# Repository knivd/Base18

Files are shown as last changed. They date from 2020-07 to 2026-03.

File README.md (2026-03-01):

# Base18
Files for my Base-18 project. <br>
https://www.youtube.com/watch?v=KffhLjCJ9JE <br>
Hackaday page: https://hackaday.io/project/166599-going-8-bit-in-style-the-pic18-computer <br>
It includes a version of the RIDE line editor, a PIC18 monitor (with disassembler!) and file system based on FatFs

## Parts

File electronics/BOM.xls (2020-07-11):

Designator | MPN/SKU | Qty | Link
C1, C2, C5, C7, C8, C10 | CL31B104KBCNNNC | 6 | https://www.digikey.co.uk/products/en?keywords=1276-1017-1-ND
C3, C4 | CC1206JRNPO9BN180 | 2 | https://www.digikey.co.uk/products/en?keywords=311-1152-1-ND
C6, C9, C11 | CL31A106KAHNNNE | 3 | https://www.digikey.co.uk/products/en?keywords=1276-1075-1-ND
D1 | 1N4148W-TP | 1 | https://www.digikey.co.uk/products/en?keywords=1N4148WTPMSCT-ND
J1, J2 | TSM-105-01-F-DV | 2 | https://www.digikey.co.uk/products/en?keywords=SAM12227-ND
J3 | PJ-036AH-SMT-TR | 1 | https://www.digikey.co.uk/products/en?keywords=CP-036AHPJCT-ND
LED1 | CMD15-21VYC/TR8 | 1 | https://www.digikey.co.uk/products/en?keywords=L62207CT-ND
LED2 | CMD15-21VRD/TR8 | 1 | https://www.digikey.co.uk/products/en?keywords=L62301CT-ND
LED3 | CMD15-21VGD/TR8 | 1 | https://www.digikey.co.uk/products/en?keywords=L62305CT-ND
MOD1 | OKL-T/3-W12P-C | 1 | https://www.digikey.co.uk/products/en?keywords=811-2709-1-ND
Q1 | DMP4051LK3 | 1 | https://www.digikey.co.uk/products/en?keywords=DMP4051LK3-13DICT-ND
Q2 | MMUN2233LT1G | 1 | https://www.digikey.co.uk/product-detail/en/on-semiconductor/MMUN2233LT1G/MMUN2233LT1GOSCT-ND/919797
R1, R2, R3, R4, R5, R7, R8, R9, R10, R12, R13, R14, R15, R16, R22, R23, R24 | RC1206JR-0710KL | 17 | https://www.digikey.co.uk/products/en?keywords=311-10KERCT-ND
R18 | RC1206FR-071KL | 1 | https://www.digikey.co.uk/products/en?keywords=311-1.00KFRCT-ND
R19 | RC1206FR-072K15L | 1 | https://www.digikey.co.uk/products/en?keywords=311-2.15KFRCT-ND
R6, R11, R17, R20 | RC1206FR-07300RL | 4 | https://www.digikey.co.uk/products/en?keywords=311-300FRCT-ND
SW1, SW2 | FSMSM | 2 | https://www.digikey.co.uk/product-detail/en/te-connectivity-alcoswitch-switches/FSMSM/450-1140-ND/525812
U1 | PIC18F87K22-I/PT | 1 | https://www.digikey.co.uk/products/en?keywords=PIC18F87K22-I%2FPT-ND
U2 | SN74LVTH573NSR | 1 | https://www.digikey.co.uk/products/en?keywords=296-13300-1-ND
Y1 | ABLS-16.000MHZ-B4-T | 1 | https://www.digikey.co.uk/products/en?keywords=535-10226-1-ND
Z1 | NFE31PT222Z1E9L | 1 | https://www.digikey.co.uk/products/en?keywords=490-2547-1-ND
X1, X2, X3, X4, X5, X6, X7, X8 | Female 2x30 SMT 2.54mm | 8 | https://www.aliexpress.com/item/32798959899.html

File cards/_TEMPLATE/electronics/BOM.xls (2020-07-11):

Designator | MPN/SKU | Qty | Link
X1 | TSW-130-07-G-D | 1 | https://www.digikey.co.uk/products/en?keywords=SAM1028-30-ND

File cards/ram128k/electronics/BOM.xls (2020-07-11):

Designator | MPN/SKU | Qty | Link
X1 | TSW-130-07-G-D | 1 | https://www.digikey.co.uk/products/en?keywords=SAM1028-30-ND
C1, C2, C3 | CL31B104KBCNNNC | 3 | https://www.digikey.co.uk/products/en?keywords=1276-1017-1-ND
U1 | IS61WV1288EEBLL-10TLI | 1 | https://www.digikey.co.uk/products/en?keywords=706-1500-ND
U2 | CD4078BM | 1 | https://www.digikey.co.uk/products/en?keywords=296-41220-1-ND

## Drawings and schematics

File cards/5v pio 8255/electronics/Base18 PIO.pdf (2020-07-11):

# A20 INT0#

# INT2# RESET#

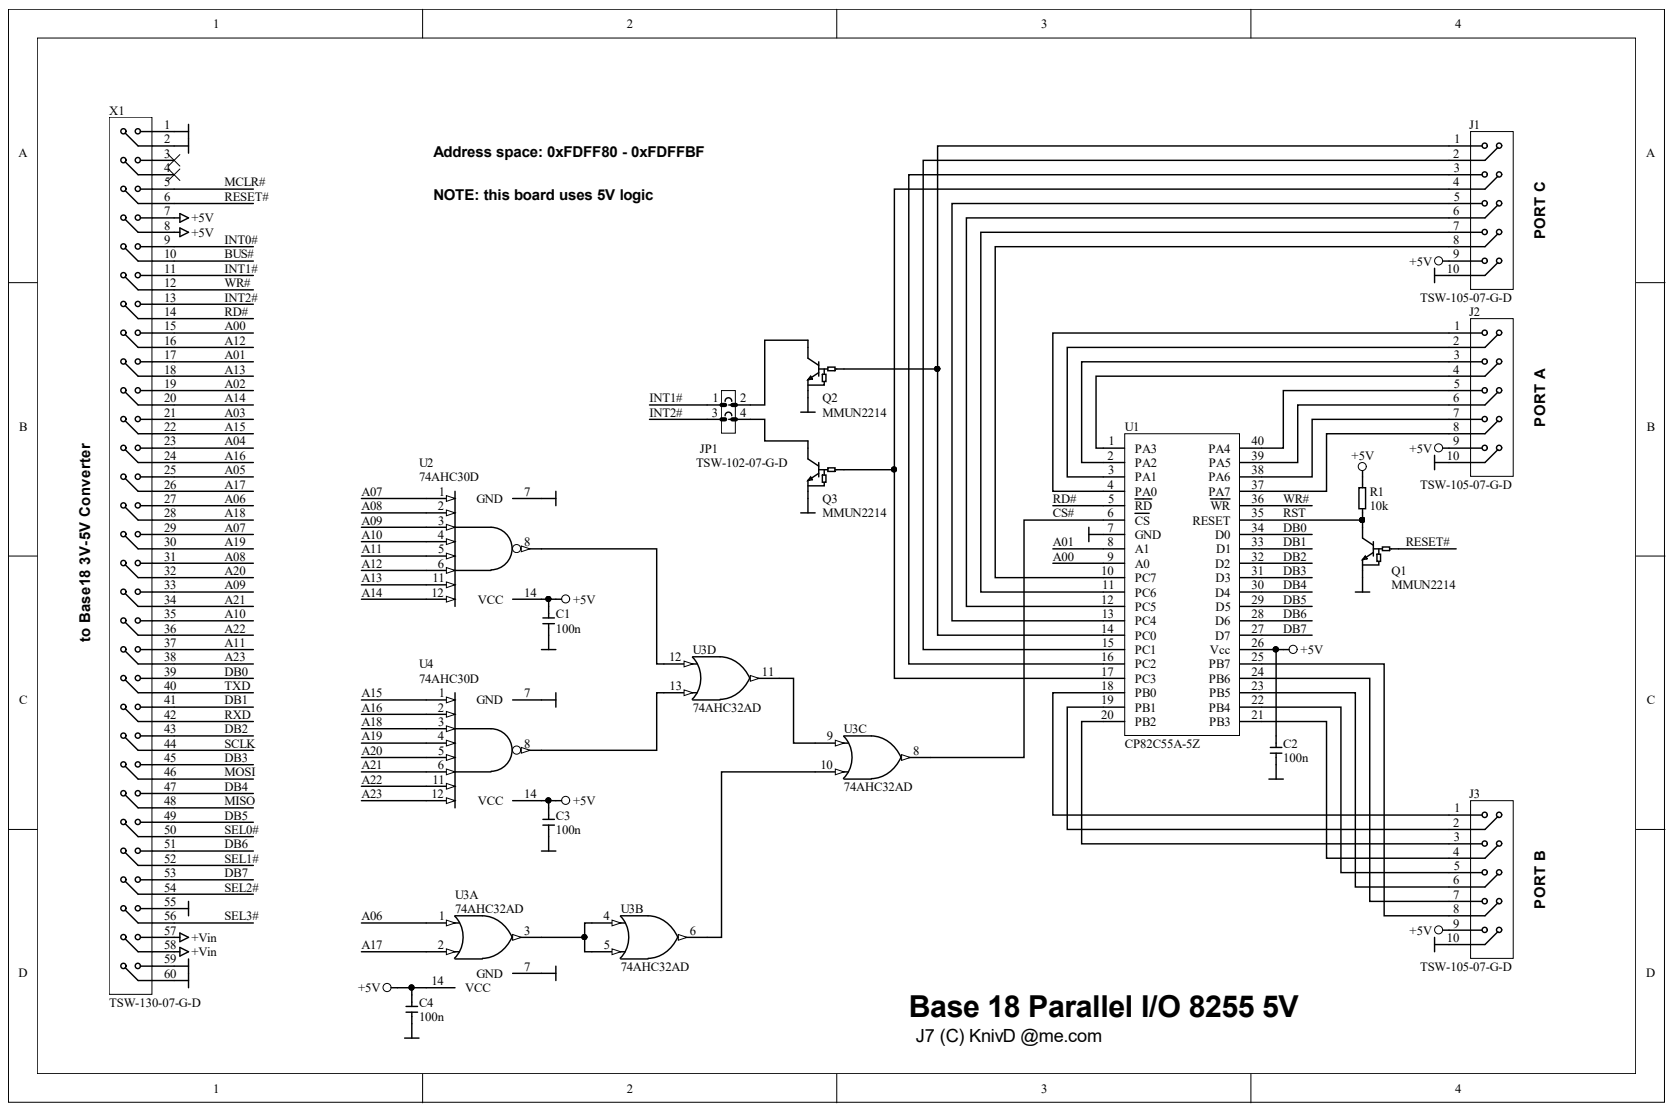
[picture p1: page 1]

NOTE: this board uses 5V logic

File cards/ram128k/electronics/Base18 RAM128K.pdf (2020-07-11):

# A20 INT0#

# INT2# RESET#

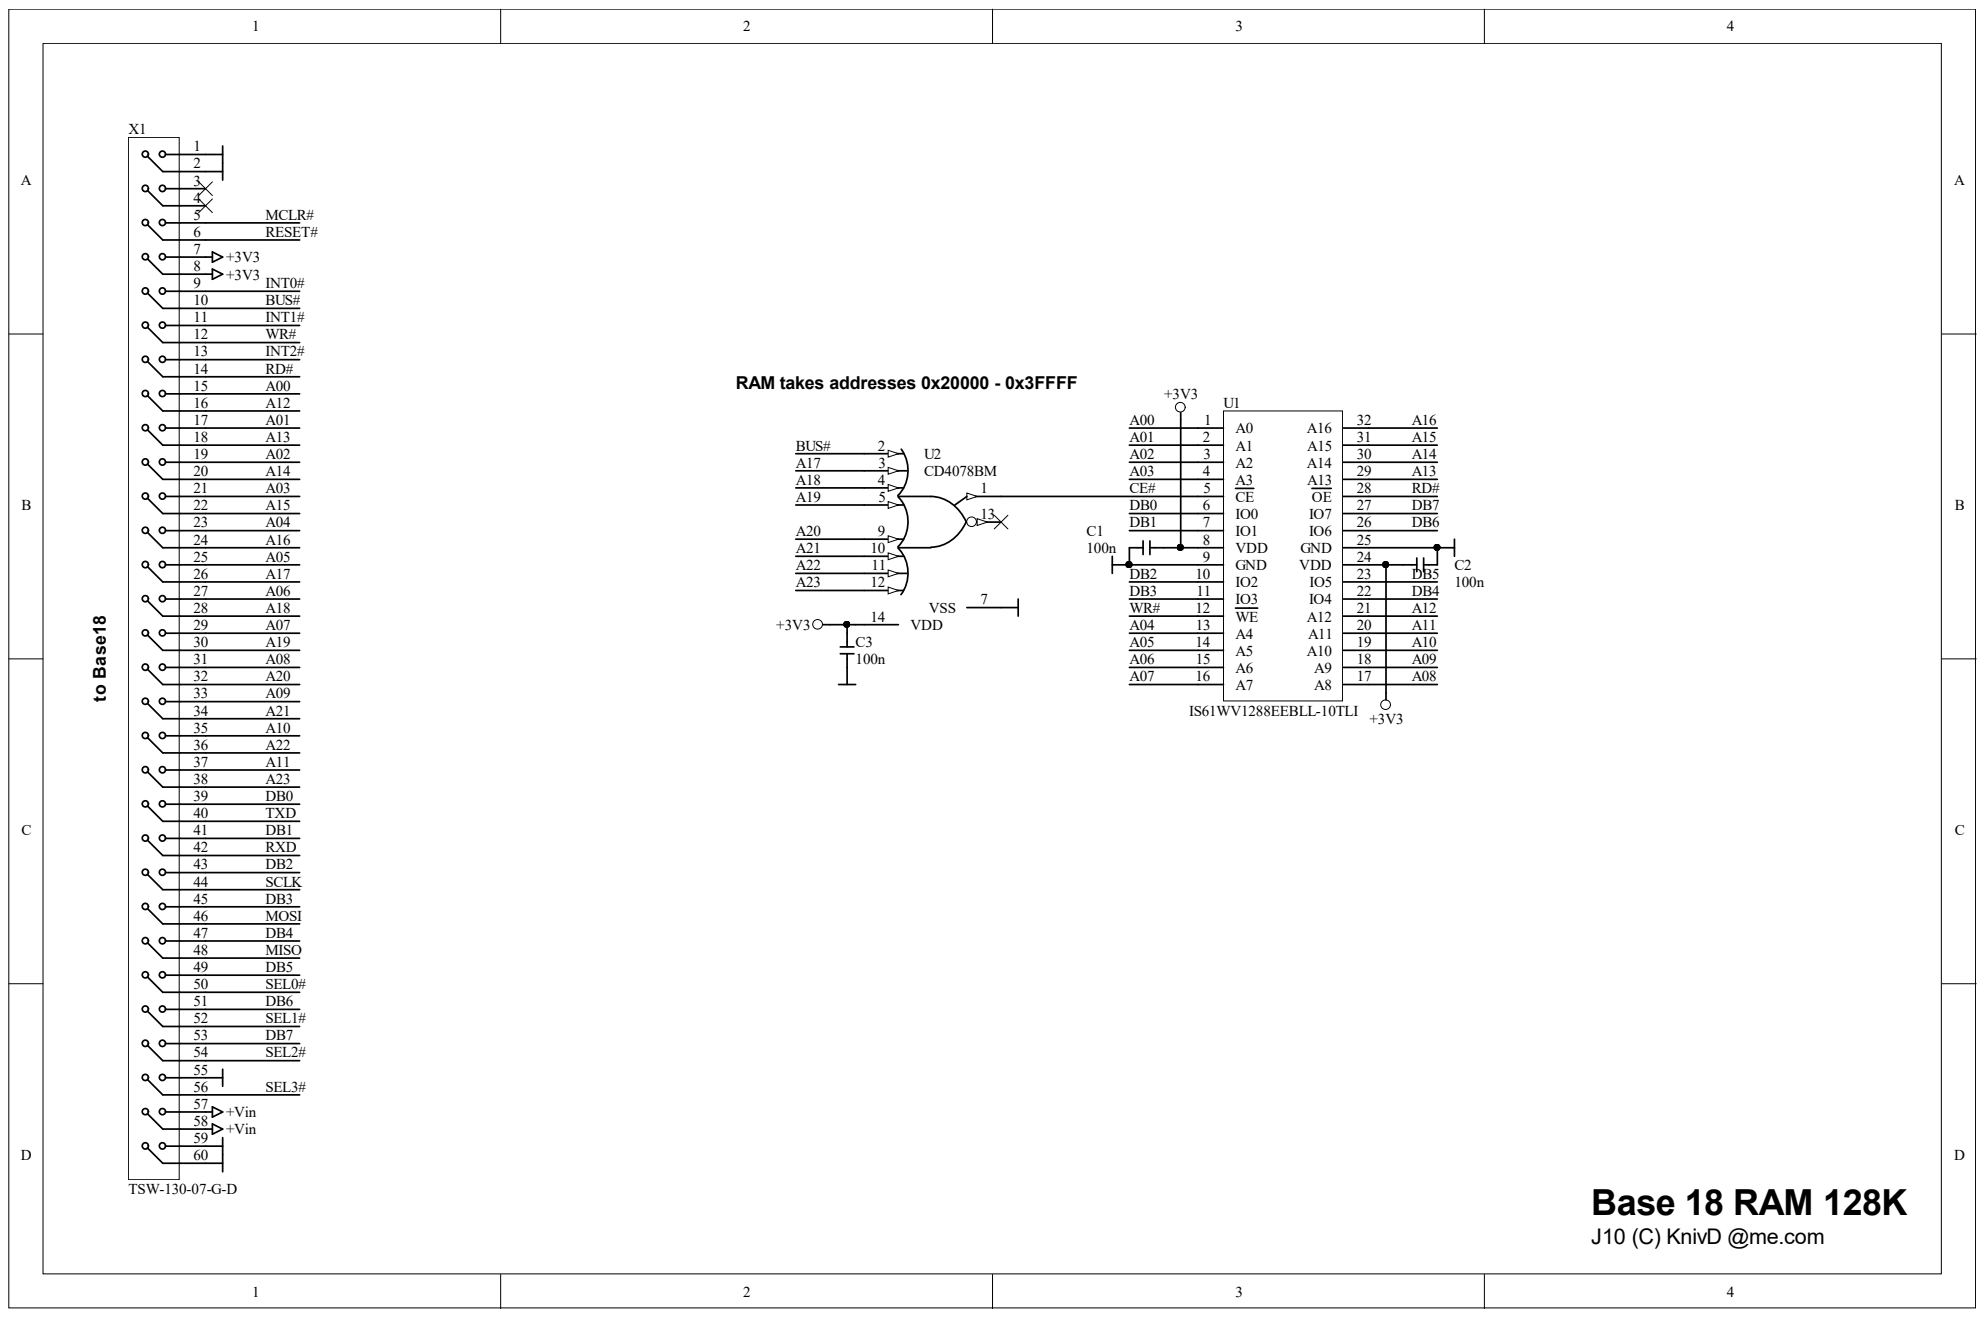
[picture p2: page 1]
Base 18 RAM 128K; INT1#; MCLR#; TXD RXD RD#; BUS# MOSI; MISO; SCLK SEL0#; SEL1#; SEL2#; SEL3#; TSW-130-07-G-D; +Vin; to Base18; VDD; GND; 23 VDD; 24 GND; IS61WV1288EEBLL-10TLI; VSS; BUS#

RAM takes addresses 0x20000 - 0x3FFFF
VDD 1423459

J10 (C) KnivD @me.com

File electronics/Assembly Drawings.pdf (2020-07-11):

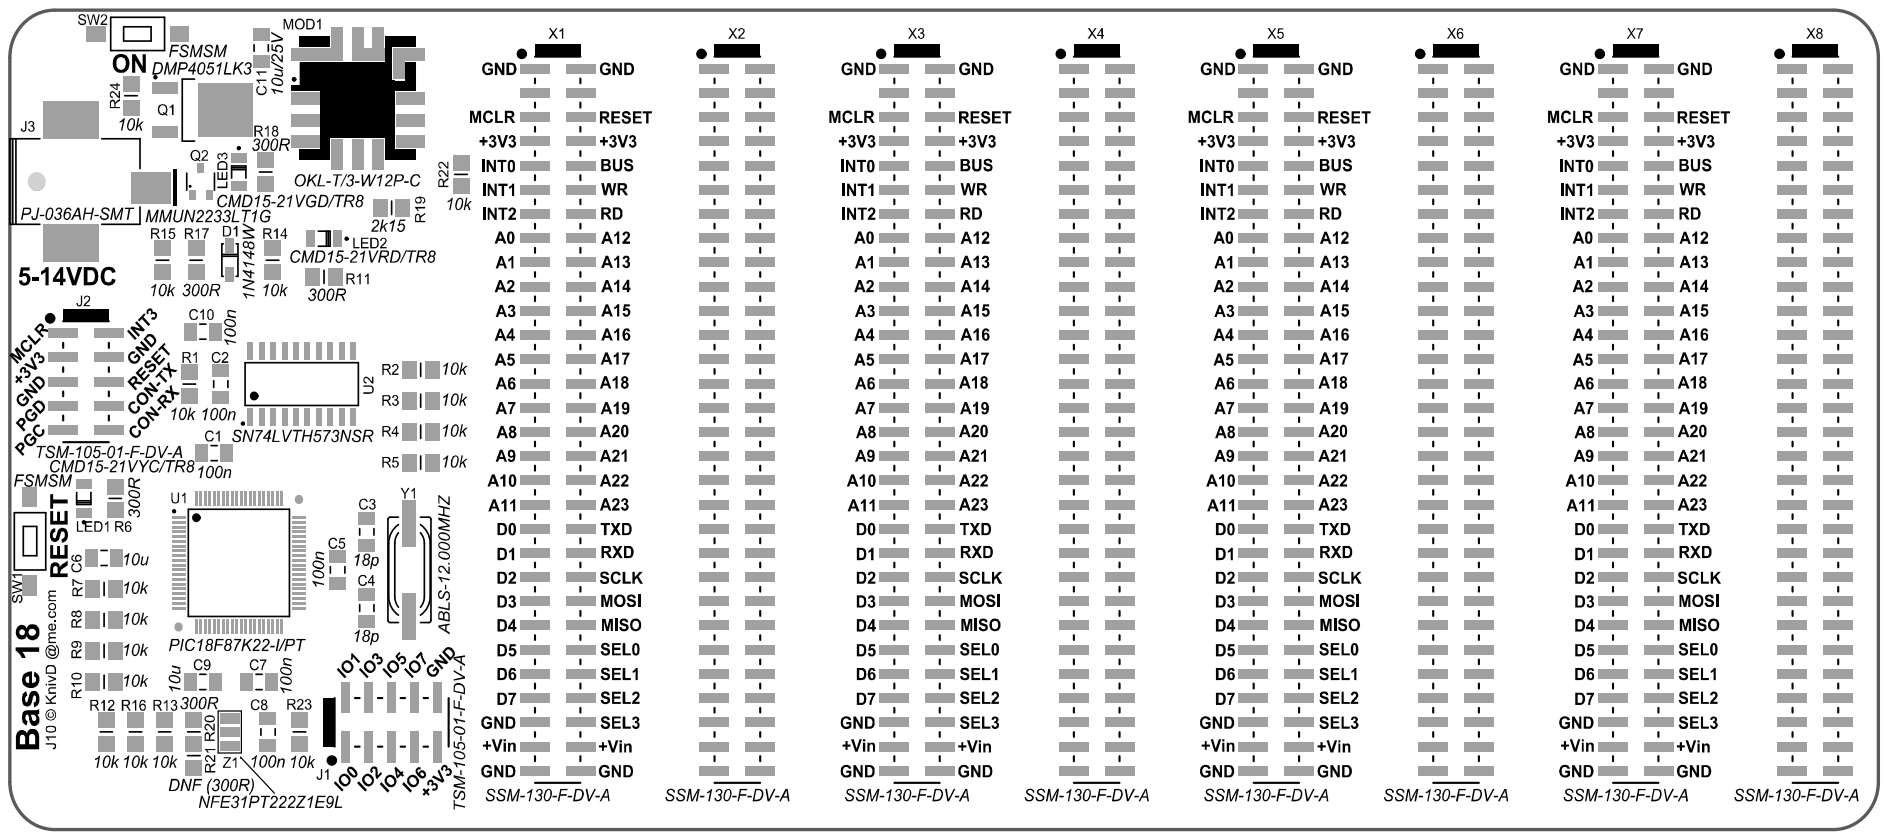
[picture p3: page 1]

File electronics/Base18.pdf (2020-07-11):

# Base 18

## J10 (C) KnivD @me.com

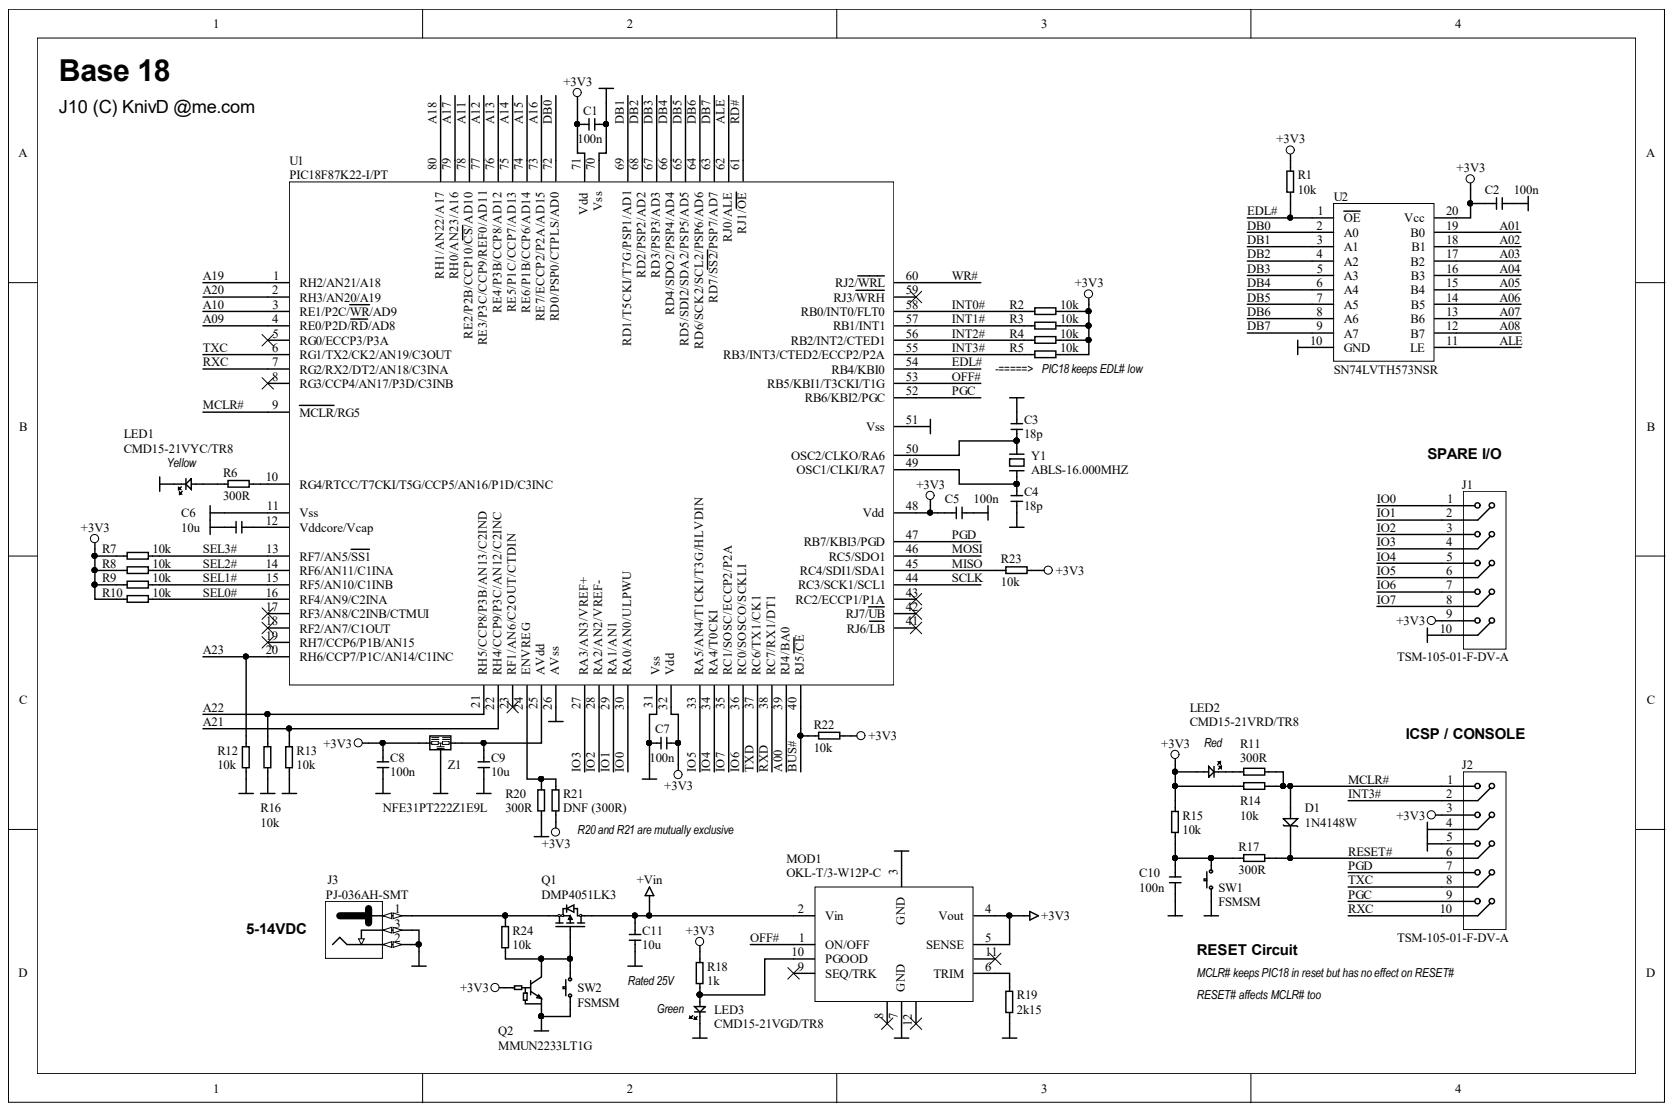
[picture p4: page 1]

MCLR# keeps PIC18 in reset but has no effect on RESET#
RESET# affects MCLR# too

# A20 INT0#

# INT2# RESET#

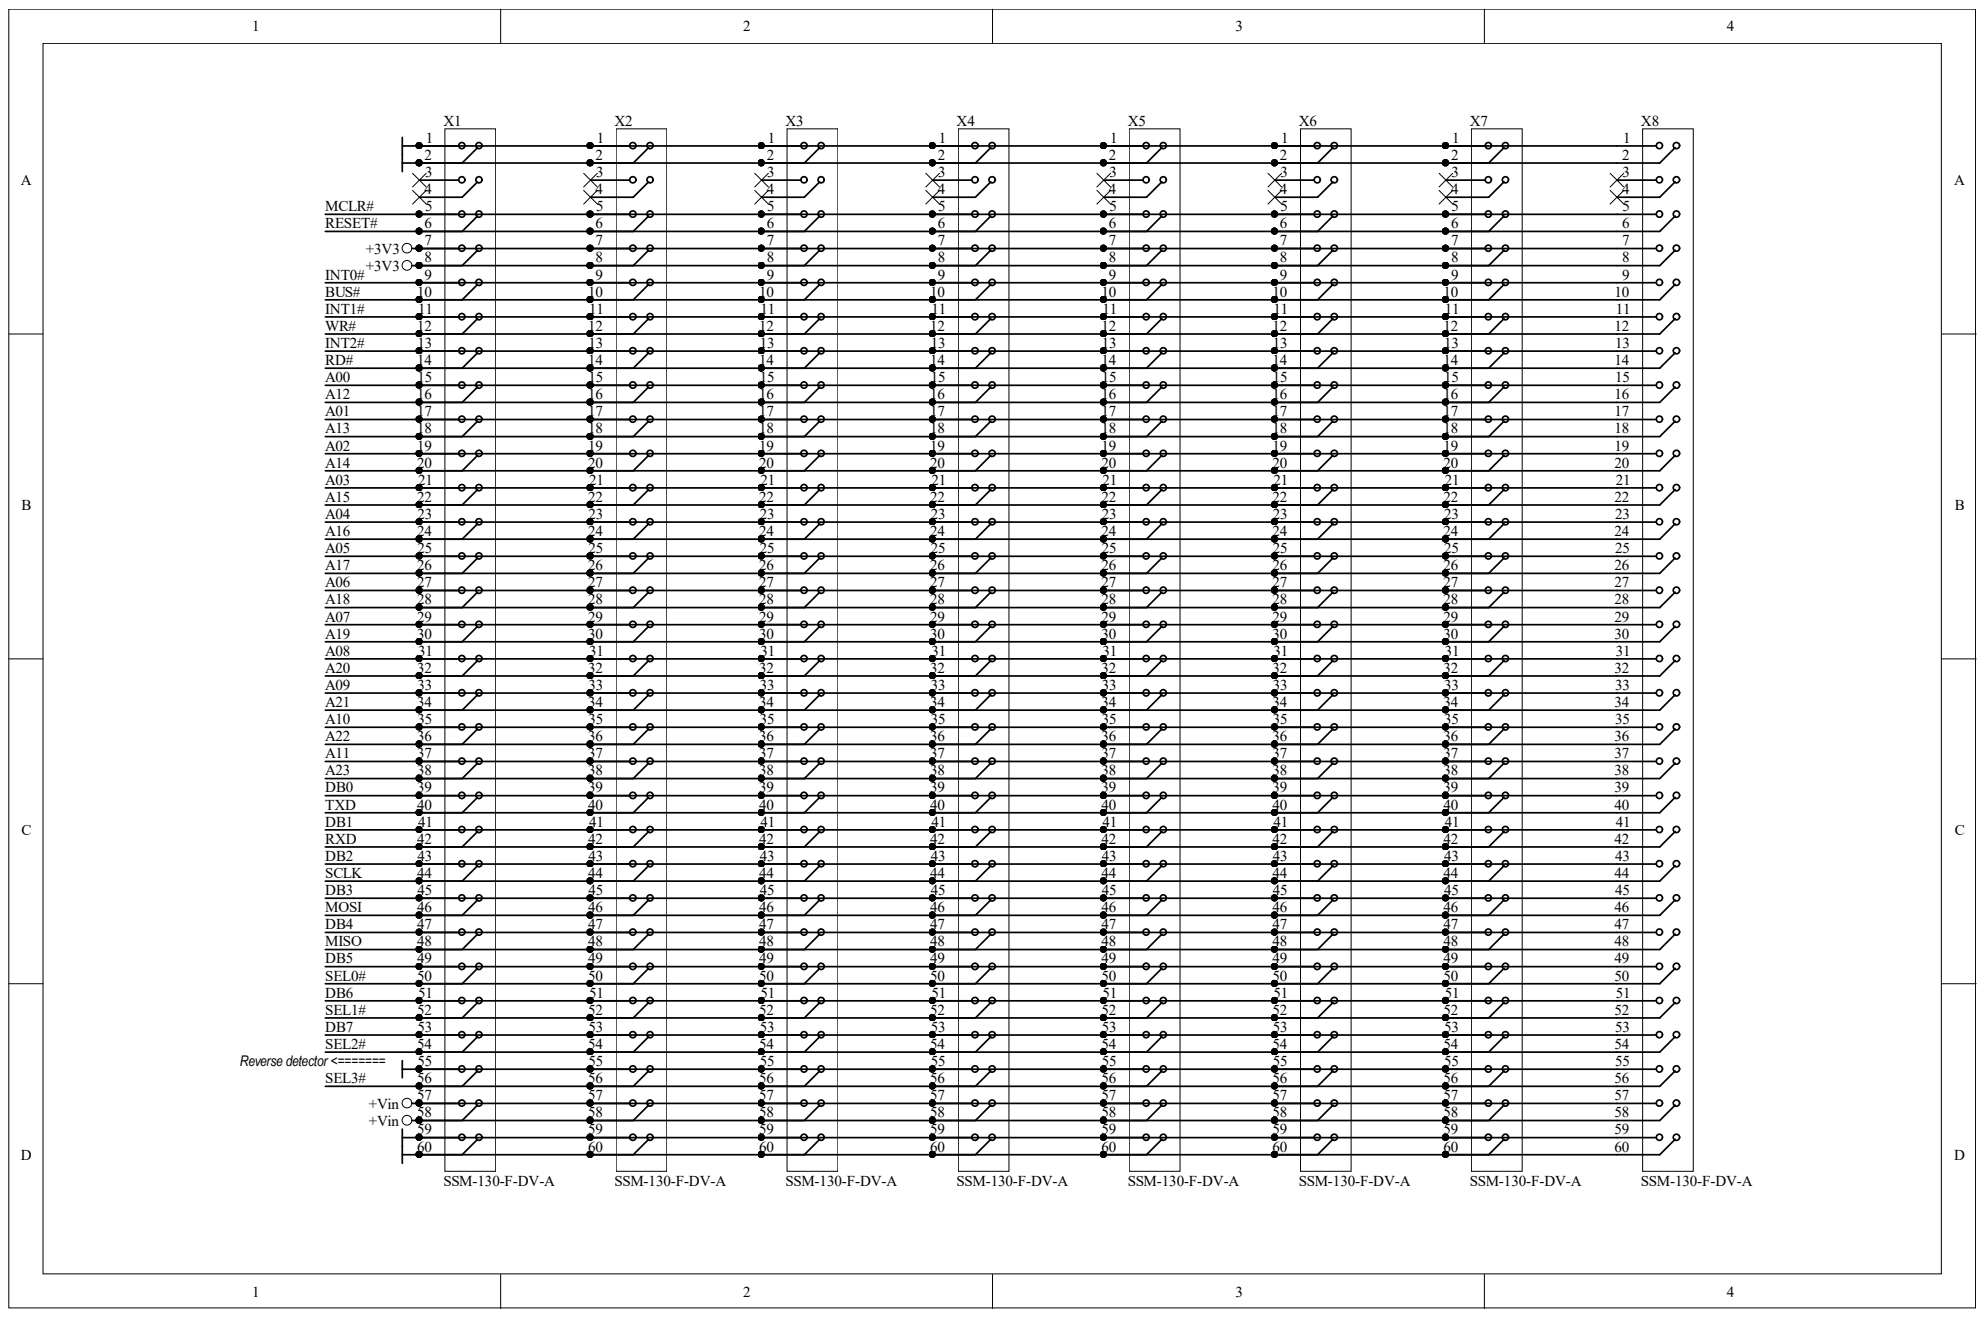
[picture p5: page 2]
INT1#; MCLR#; TXD RXD RD#; BUS# MOSI; MISO; SCLK SEL0#; SEL1#; SEL2#; SEL3#; SSM-130-F-DV-A; Reverse detector <=======; +Vin +Vin; PIX101; PIX102; PIX103; PIX104; PIX105; PIX106; PIX107; PIX108; PIX109; PIX1010; PIX1011; PIX1012; PIX1013; PIX1014; PIX1015; PIX1016; PIX1017; PIX1018; PIX1019; PIX1020; PIX1021; PIX1022; PIX1023; PIX1024; PIX1025; PIX1026; PIX1027; PIX1028; PIX1029; PIX1030; PIX1031; PIX1032; PIX1033; PIX1034; PIX1035; PIX1036; PIX1037; PIX1038; PIX1039; PIX1040; PIX1041; PIX1042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

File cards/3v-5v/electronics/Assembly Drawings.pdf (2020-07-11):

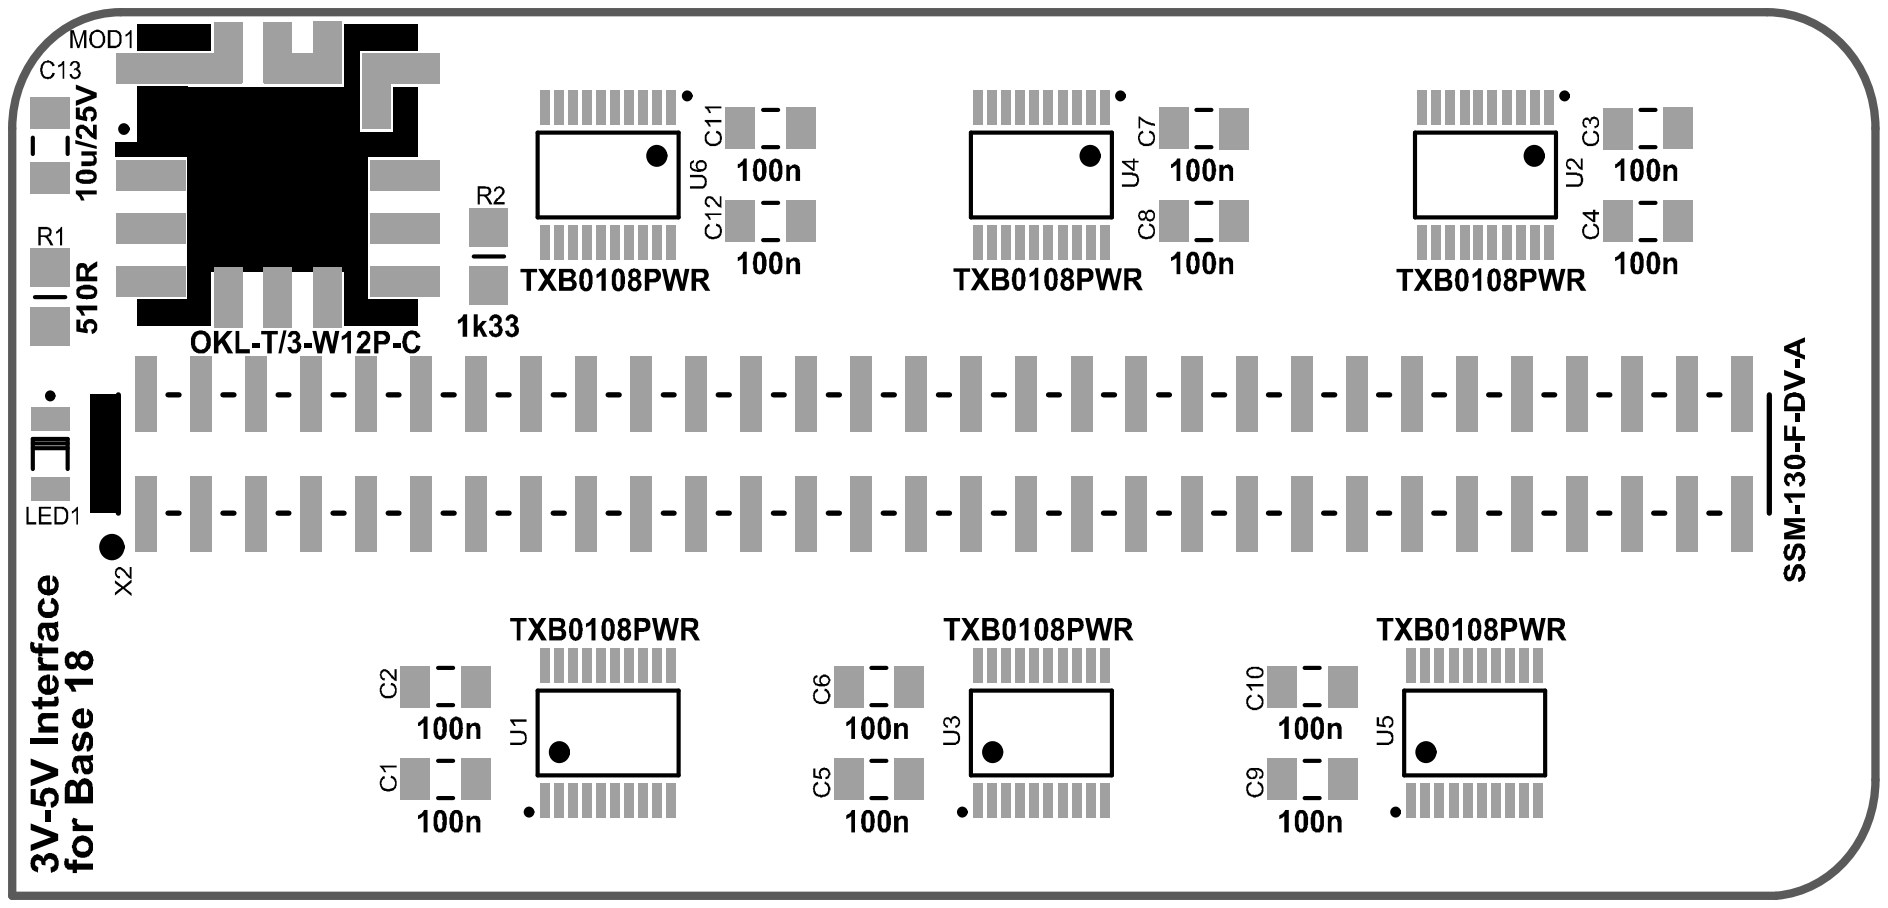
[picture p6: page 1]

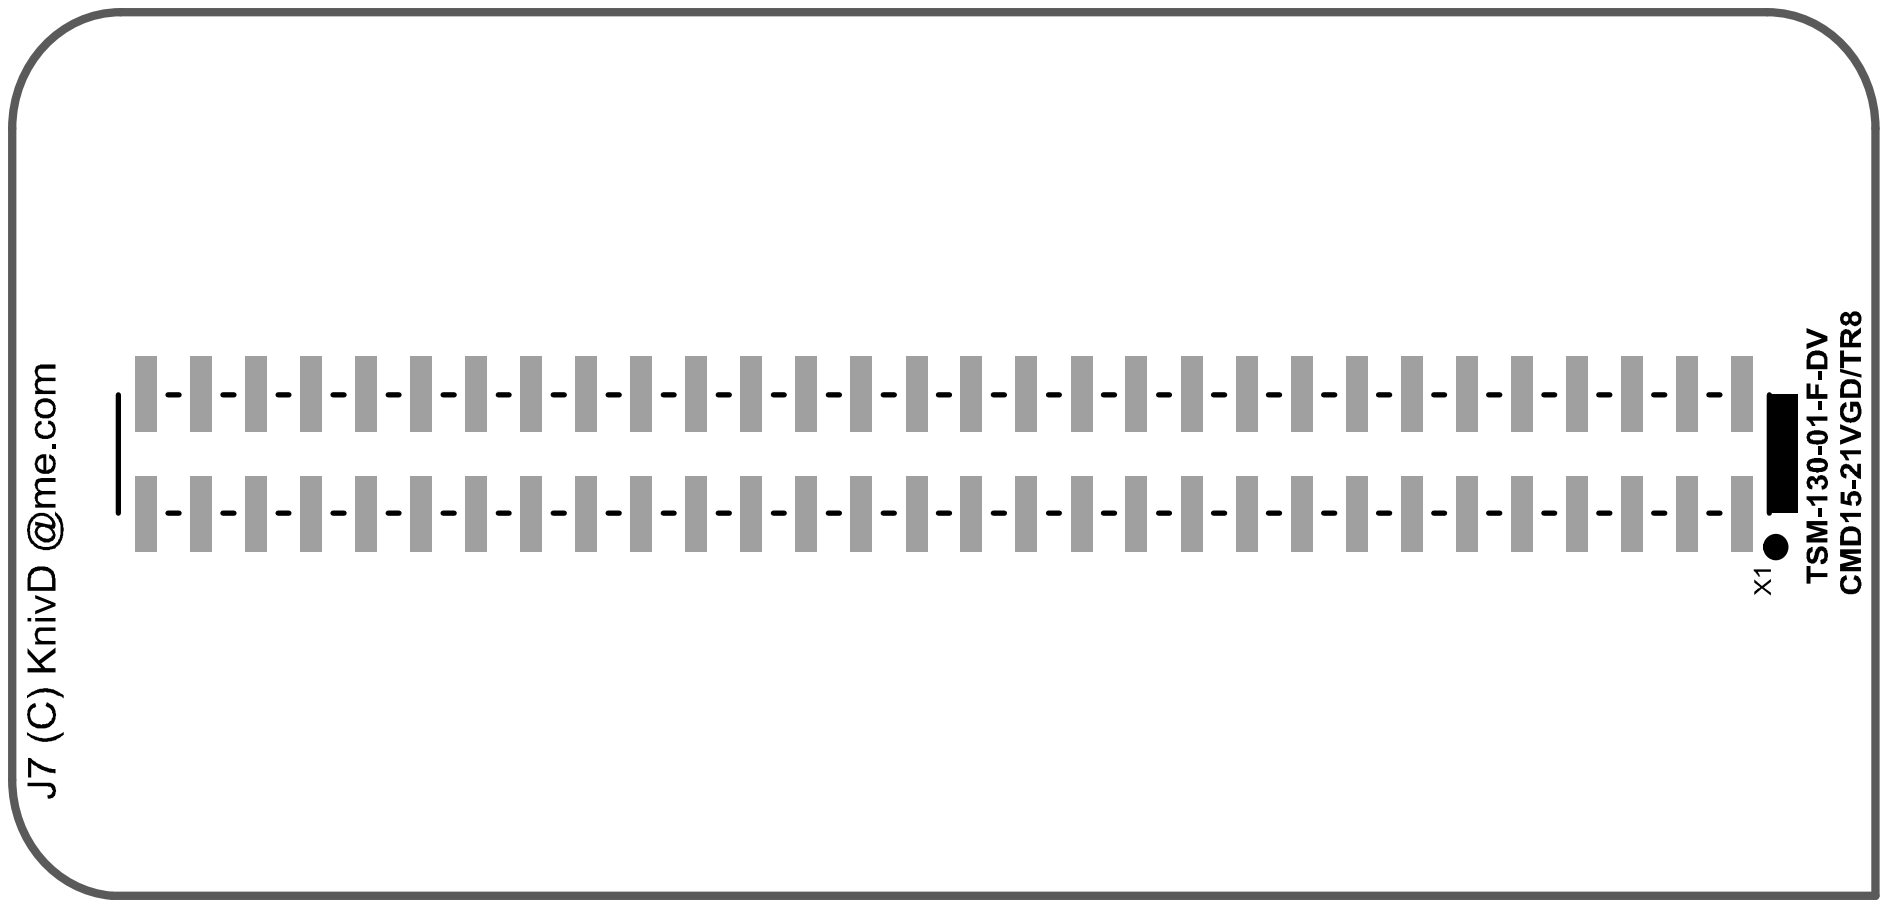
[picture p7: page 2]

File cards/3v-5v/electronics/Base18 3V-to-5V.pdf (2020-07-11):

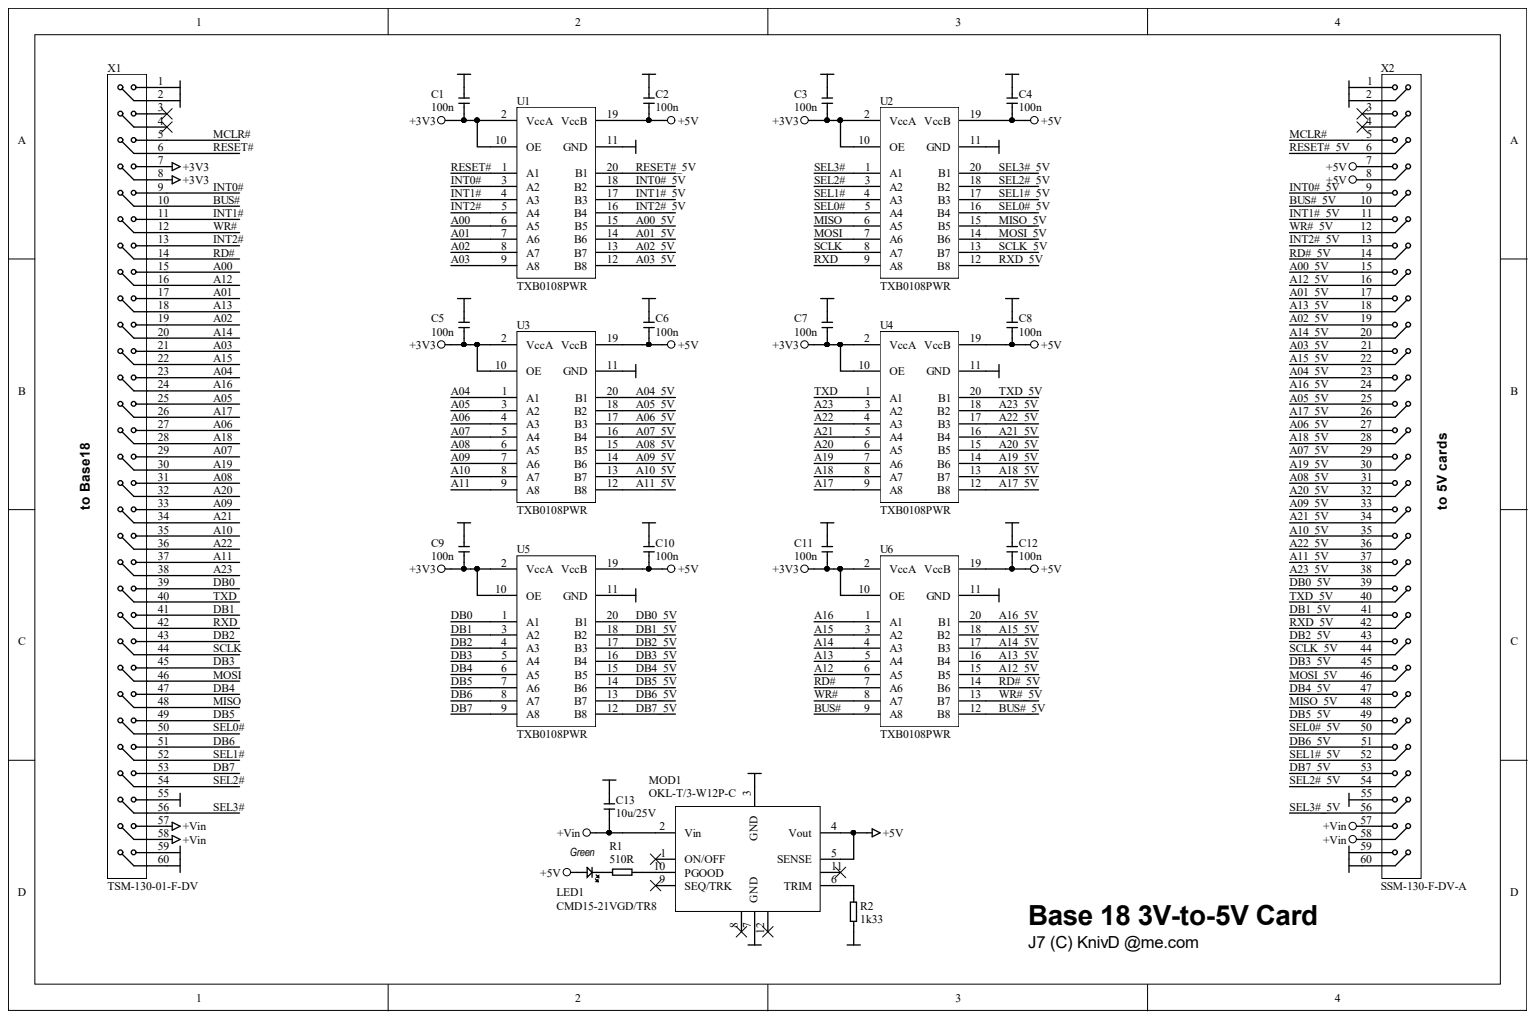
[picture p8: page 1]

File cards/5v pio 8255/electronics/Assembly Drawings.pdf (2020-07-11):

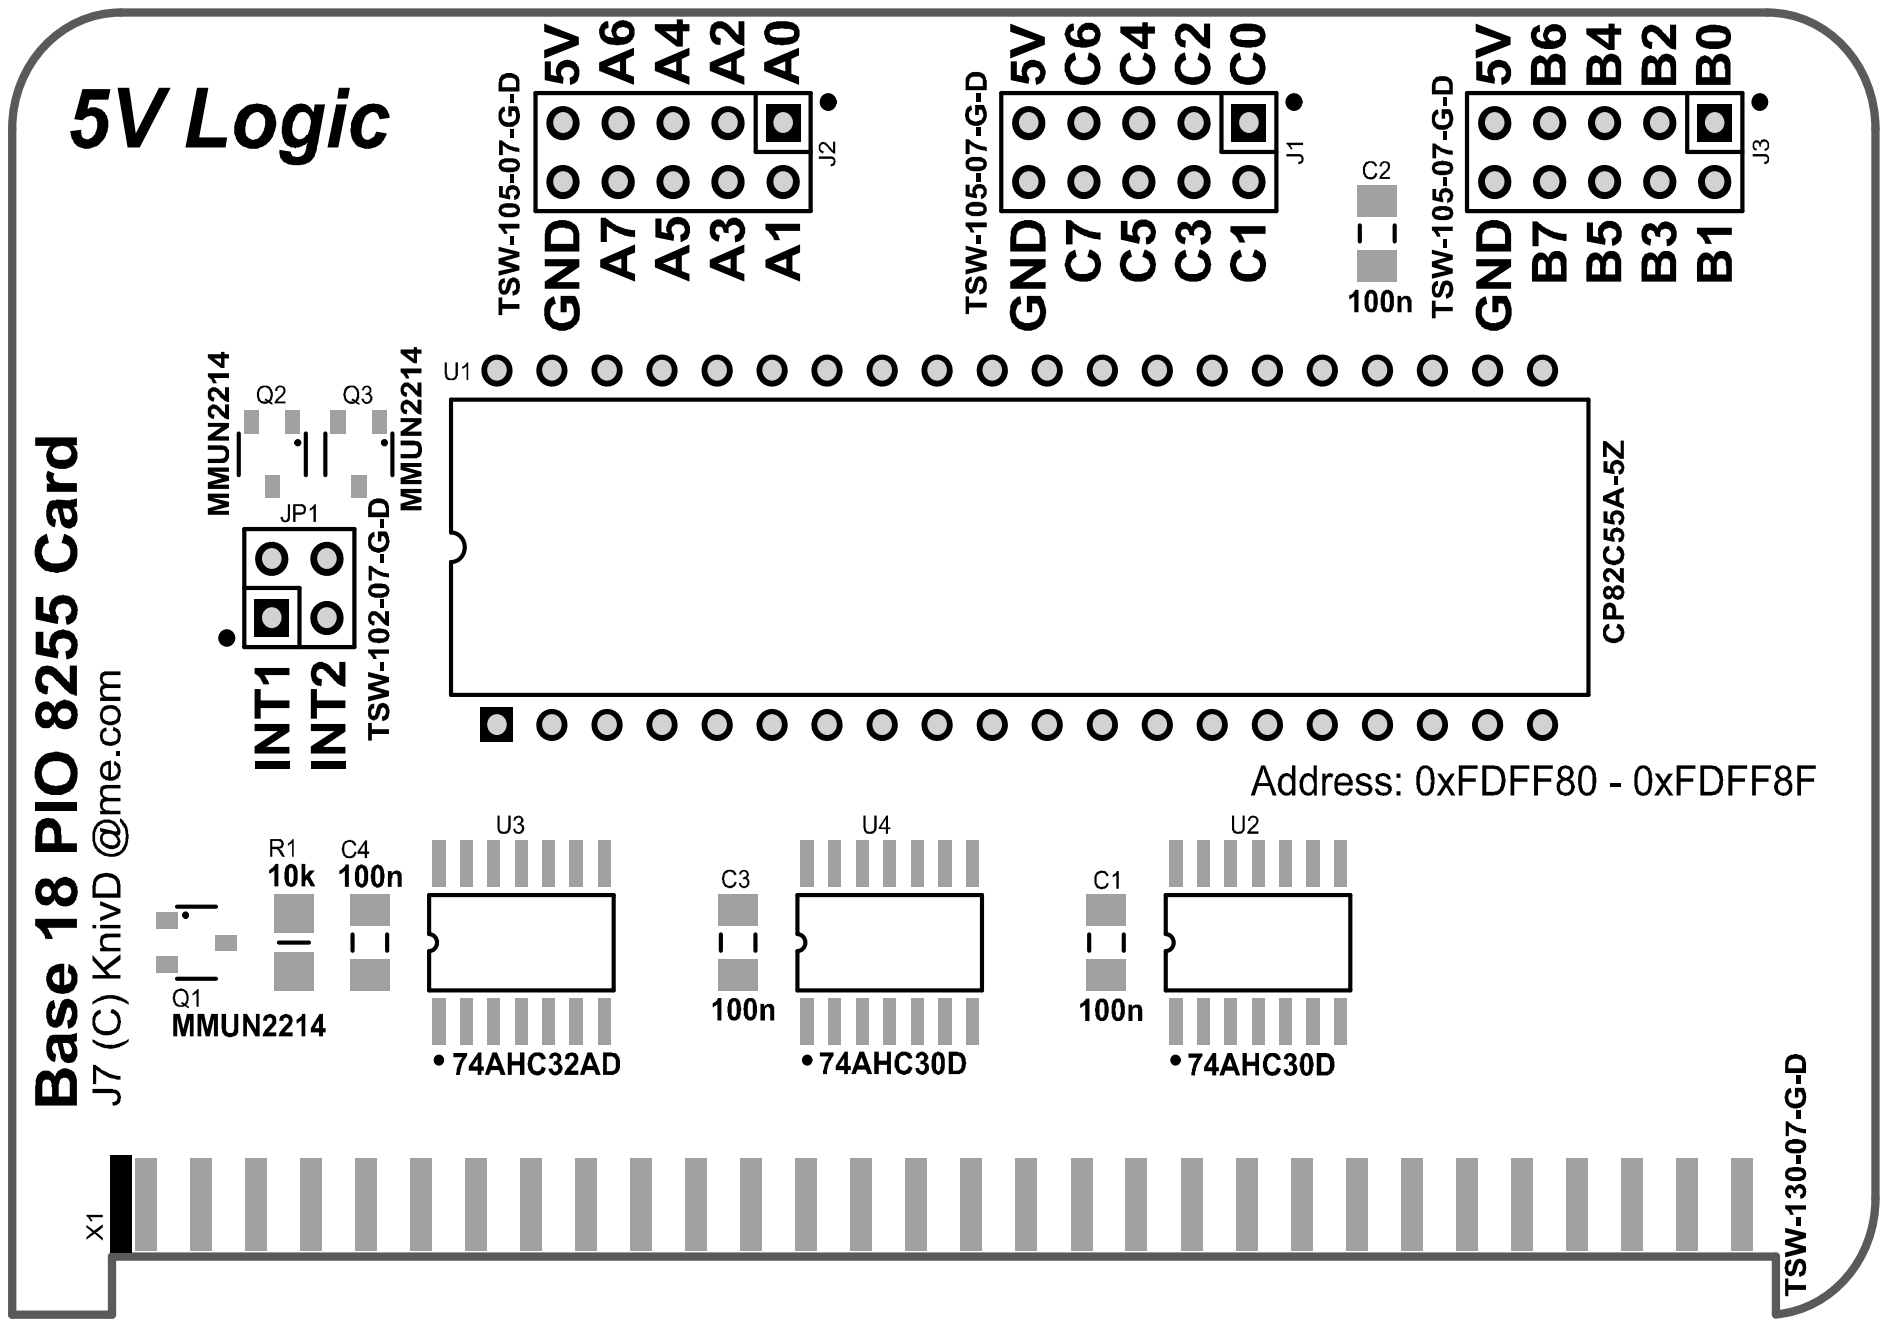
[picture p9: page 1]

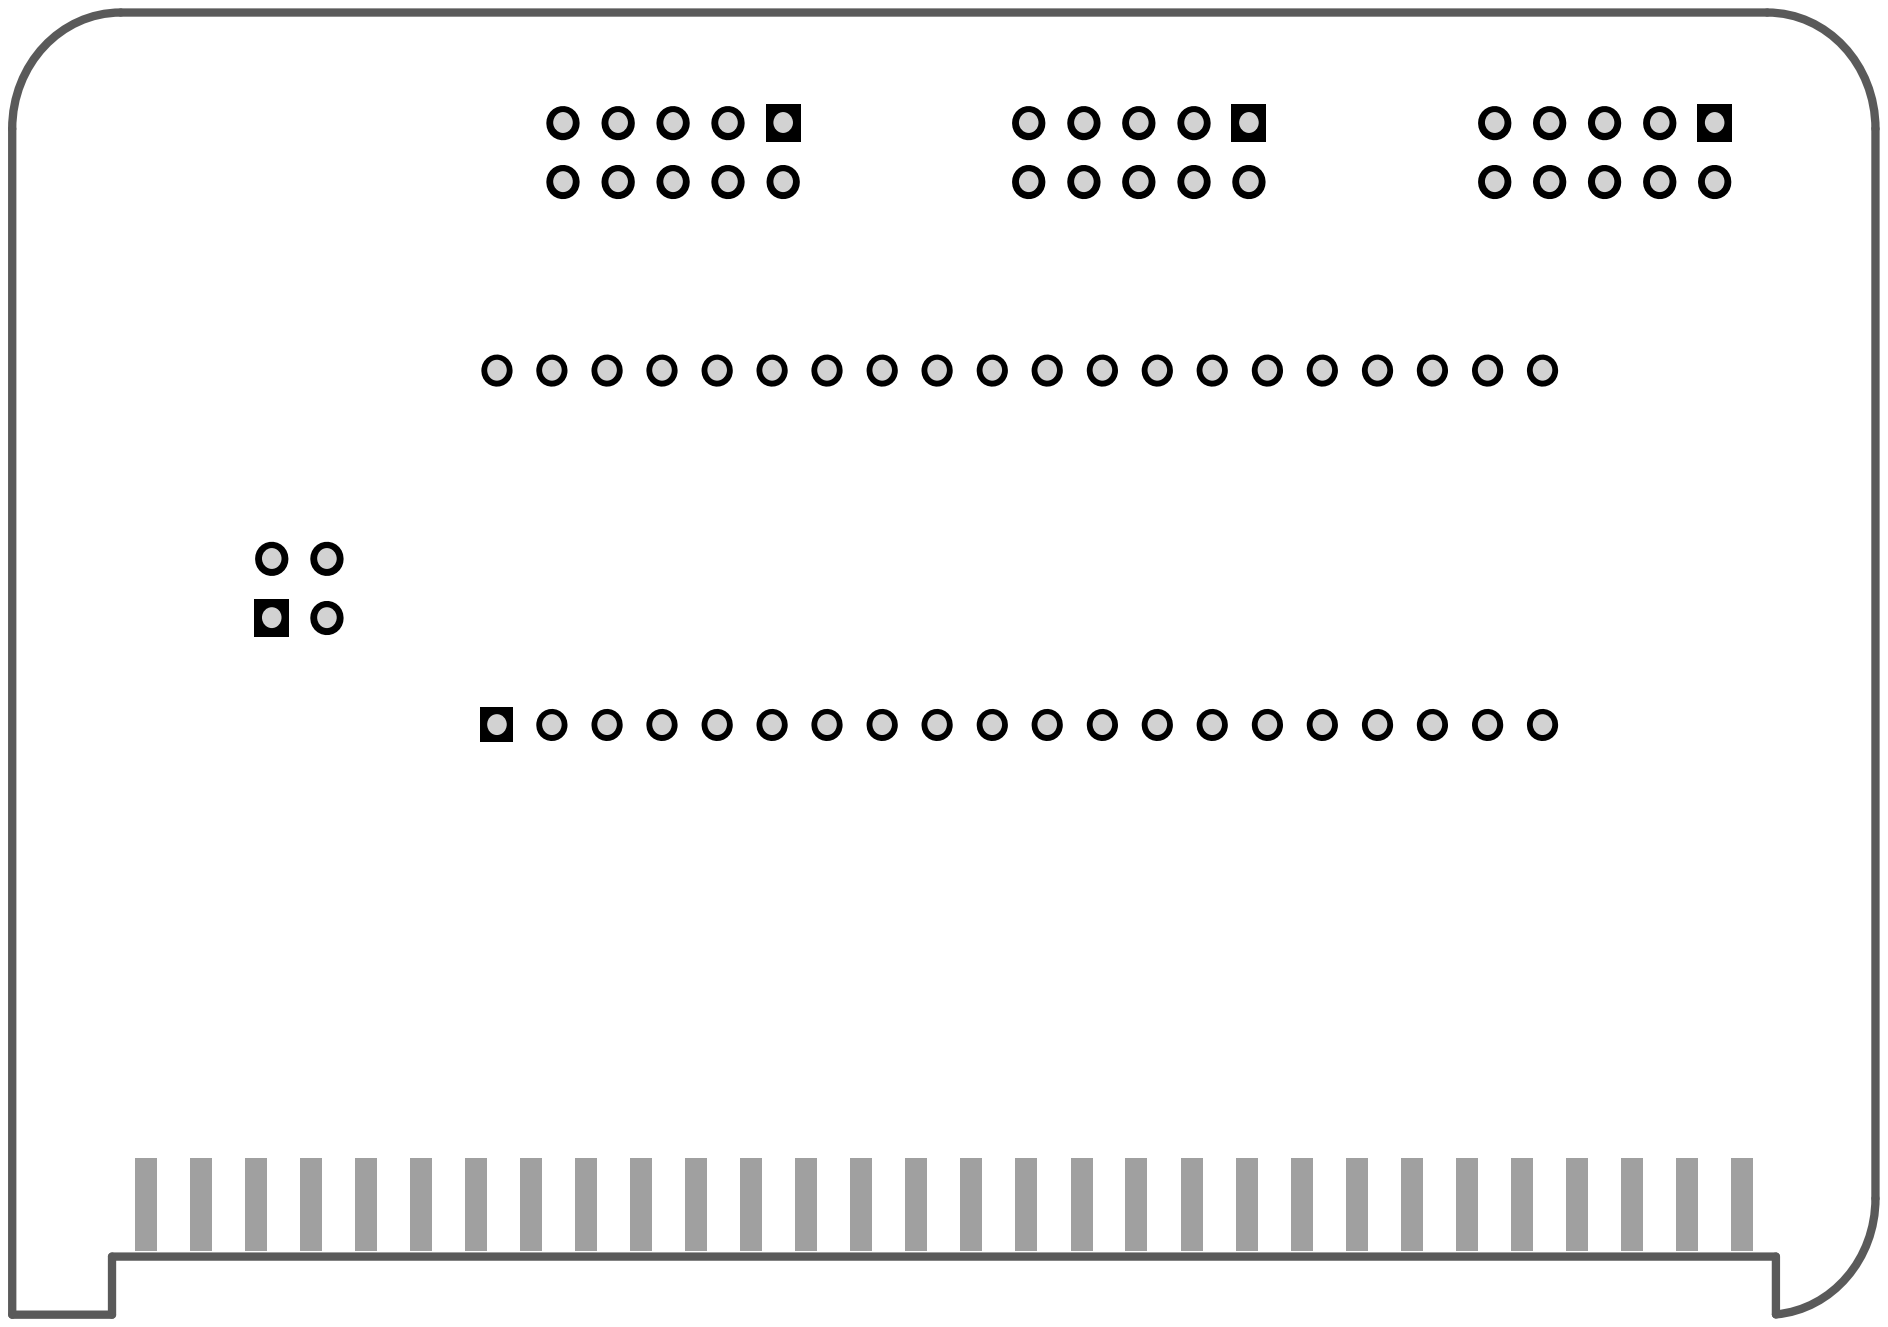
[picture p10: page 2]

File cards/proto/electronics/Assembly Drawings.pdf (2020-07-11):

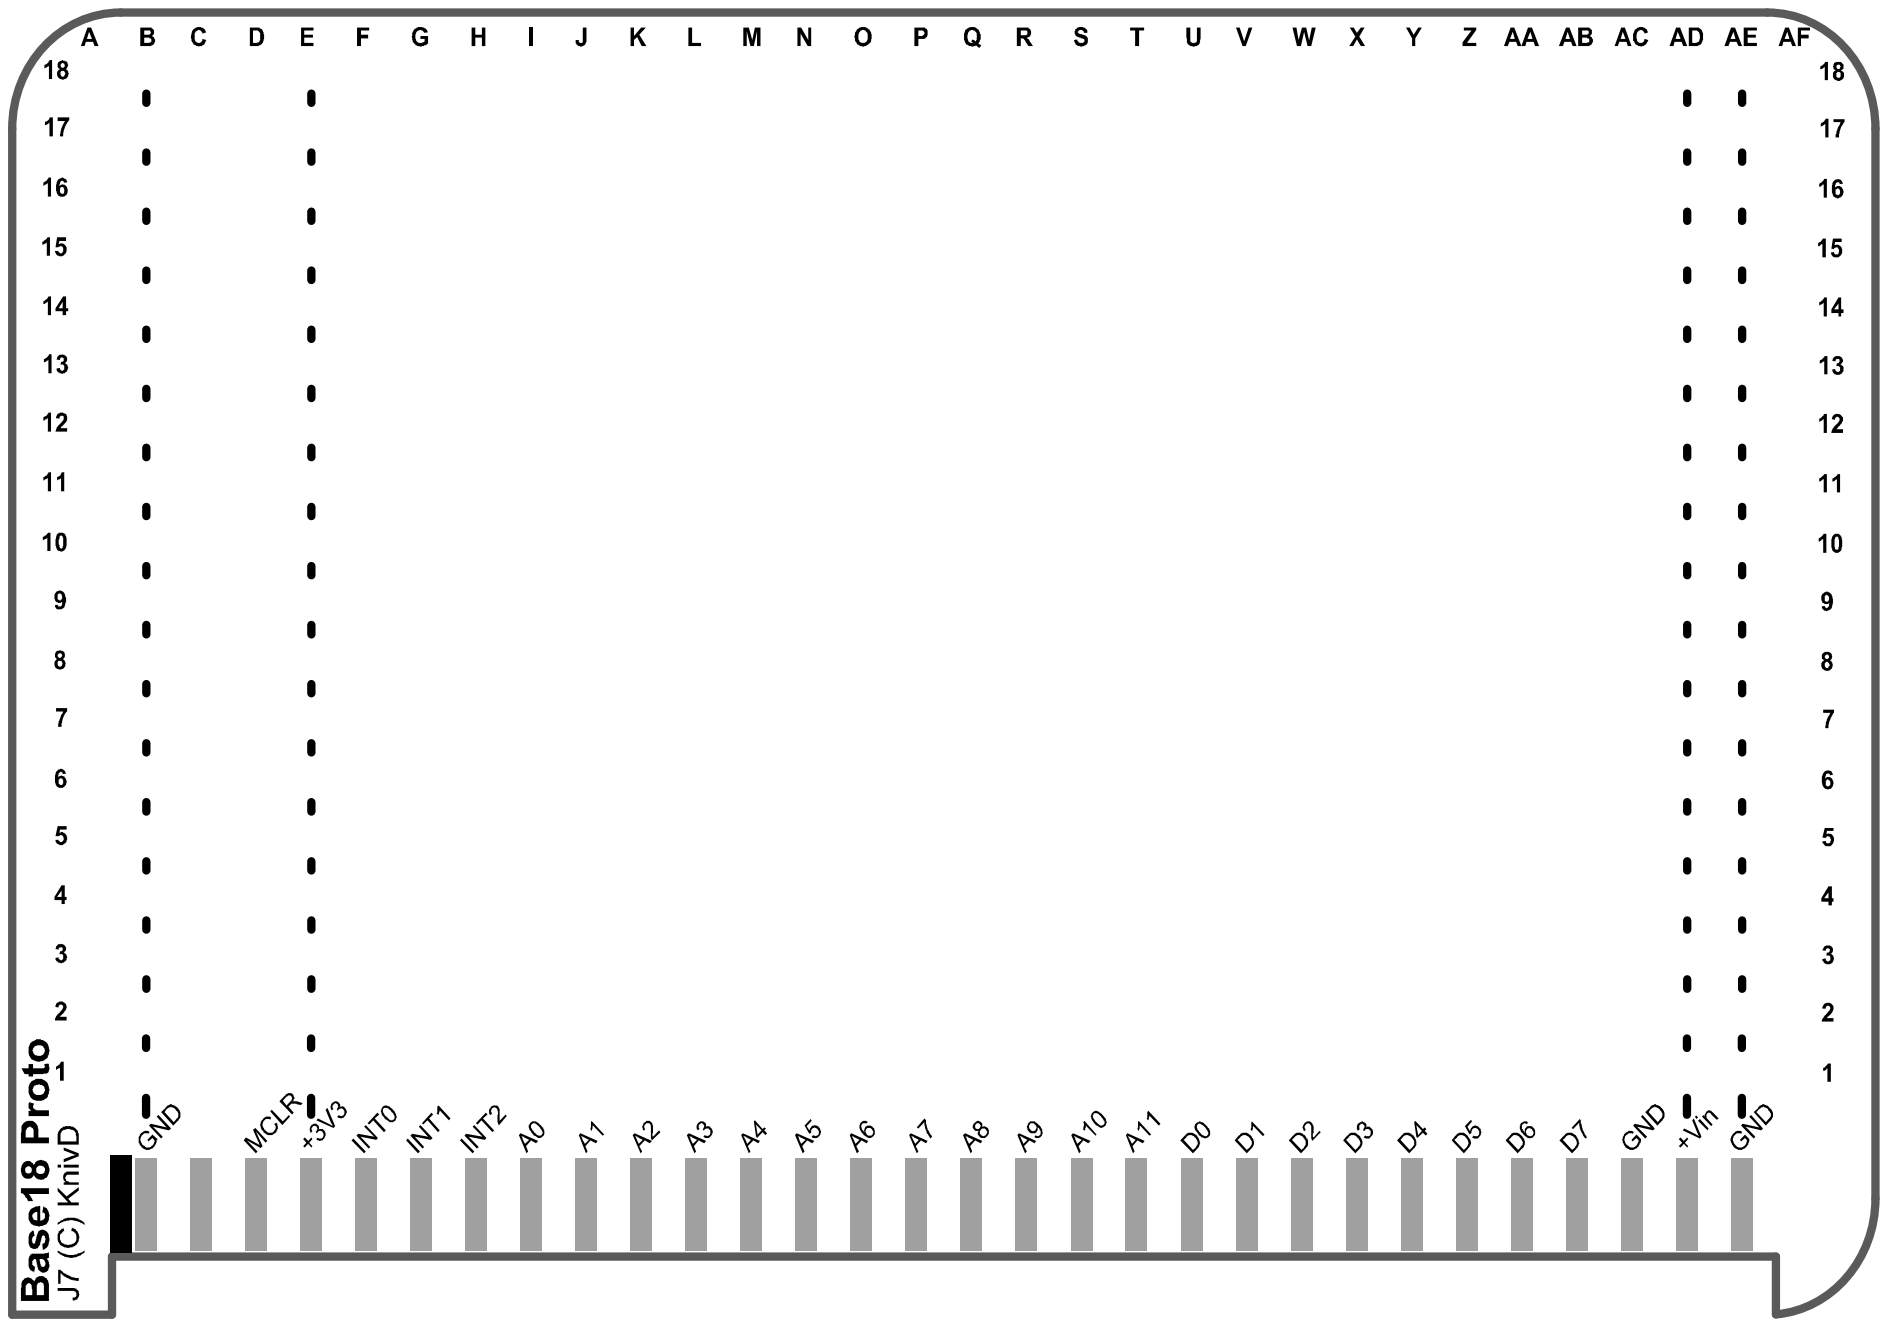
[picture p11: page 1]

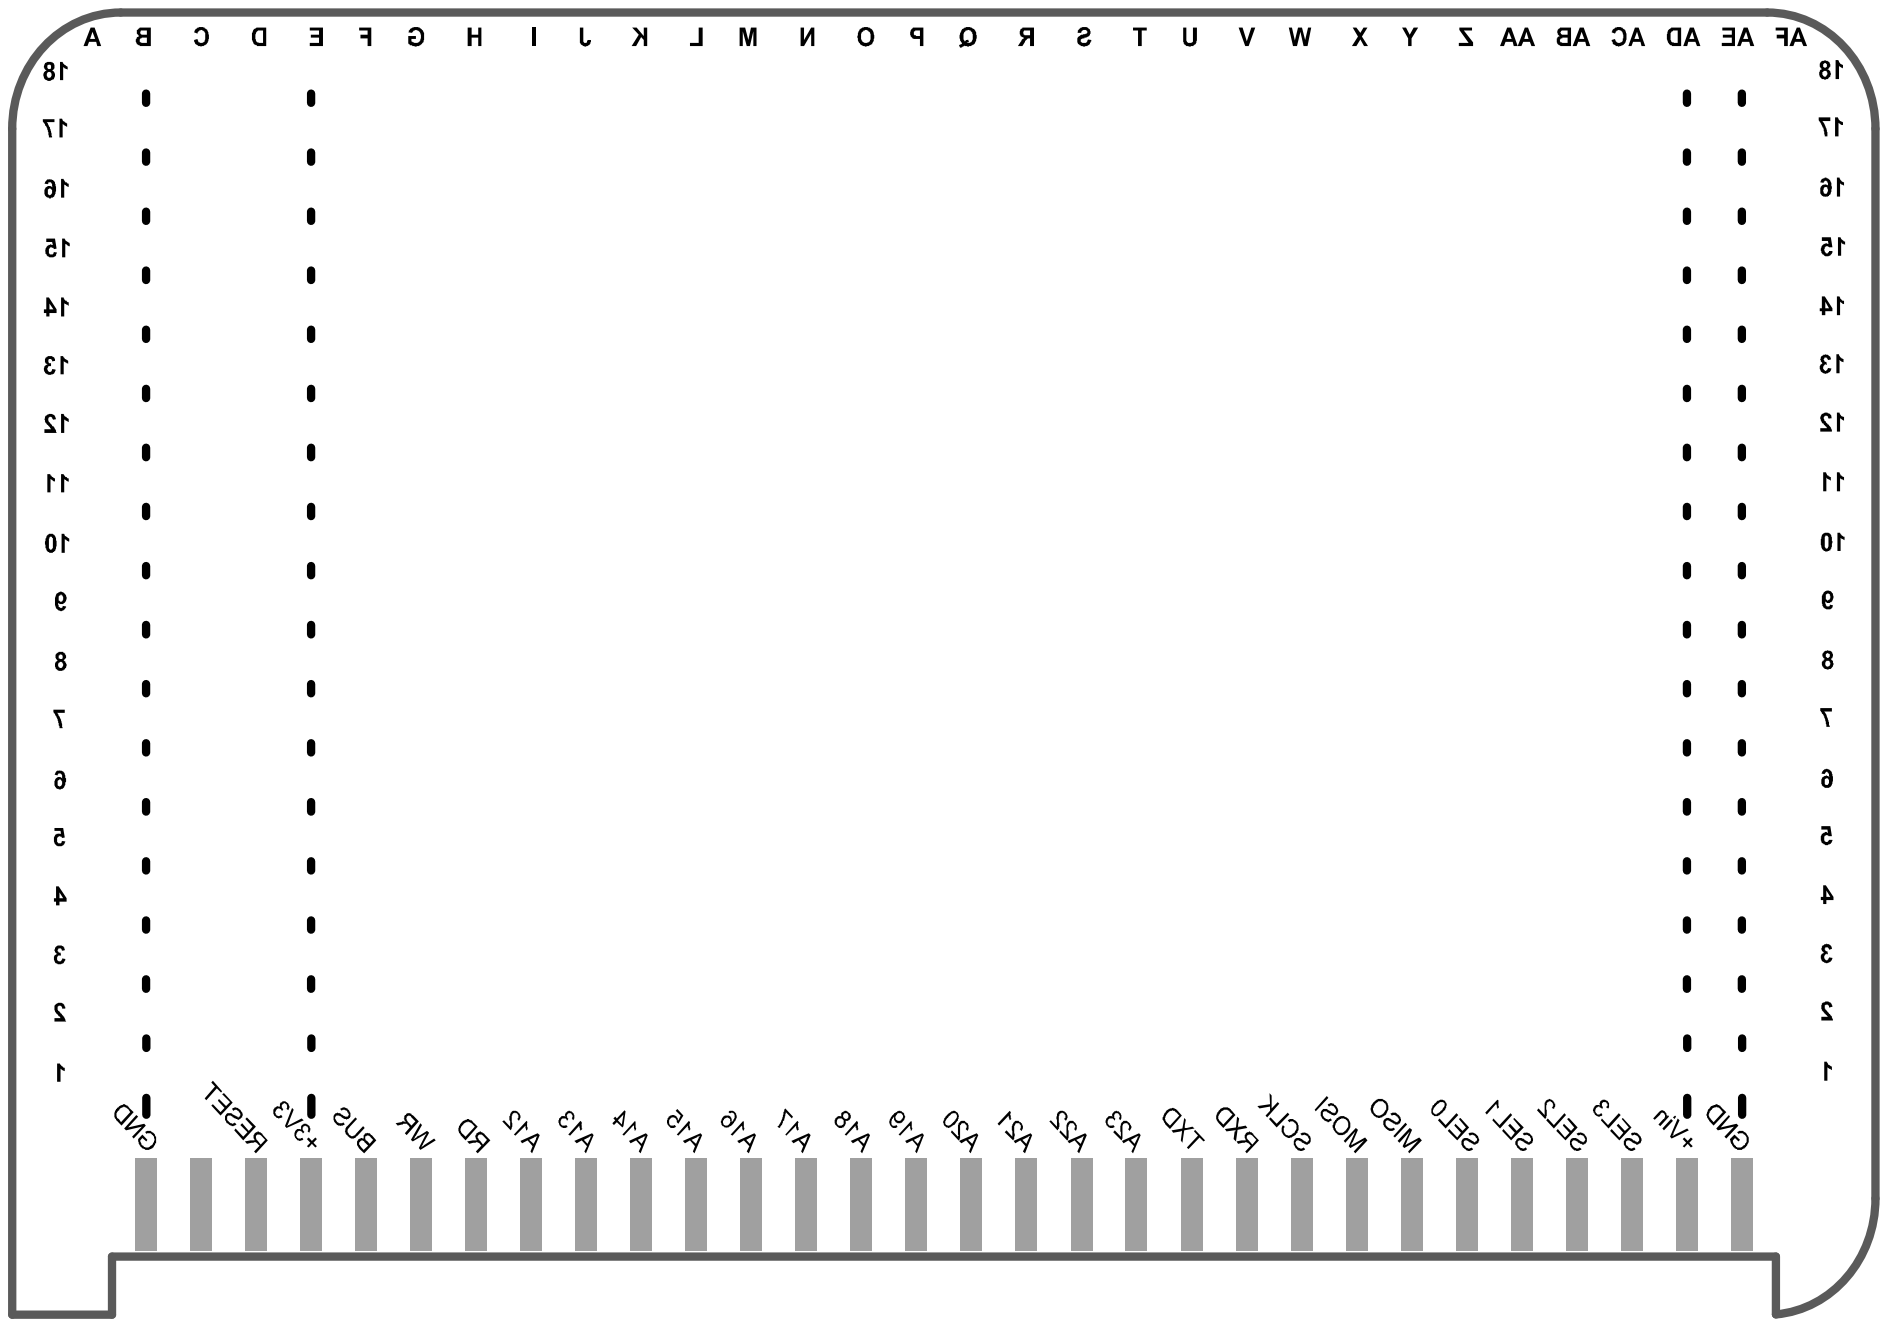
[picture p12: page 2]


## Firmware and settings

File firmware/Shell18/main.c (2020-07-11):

#include "main.h"
#include "console.h"
#include "hardware.h"
#include "xmem.h"

#ifdef INCLUDE_FILES
	#include "fileops.h"
#endif

#ifdef INCLUDE_MONITOR
	#include "monitor.h"
#endif

#ifdef INCLUDE_RIDE
	#include "ride.h"
#endif

#ifndef SANDBOX
	#include "bios.h"
#endif

// prompt string in the main console
uint8_t PROMPT[16] = "|_ ";

// version information constant
const uint32_t VER_INFO = VERSION;


// skip whitespace characters in string
// (preinc) specifies the minimum number of characters that definitely need to be skipped
void skip(char **source, uint32_t preinc) {
	char *src = *source;
	while(*src && preinc--) src++;
	while(*src) {
		if(strchr(" \t\v\r\n", *src)) src++;
		else break;
	}
	*source=src;
}


// main function
// ===========================================================================

#ifndef FF_MAX_LFN
#define FF_MAX_LFN 255
#endif

int main(void) {

	// system initialisation
	coldInit();
	#ifndef SANDBOX

		linksC();	// create the BIOS jump table on the first run

		// ====================================================

		// This is a completely bogus check that will never get executed
		// The only reason for it is to trick the compiler to not remove functions that
		// are needed for inclusion but have not been used elsewhere in the code yet
		if(PROMPT[strlen((char *) PROMPT)] == '\a') {
			getche();
			peekch();
			ungetch(0);
			#ifdef INCLUDE_FILES
				f_truncate(NULL);
				f_sync(NULL);
				f_findfirst(NULL, NULL, NULL, NULL);
				f_findnext(NULL, NULL);
				f_stat(NULL, NULL);
				f_chmod(NULL, 0, 0);
				f_utime(NULL, NULL);
				f_getlabel(NULL, NULL, NULL);
				f_setlabel(NULL);
				f_forward(NULL, NULL, 0, NULL);
				f_expand(NULL, 0, 0);
				f_putc(0, NULL);
				f_puts(NULL, NULL);
				f_printf(NULL, NULL);
				f_gets(NULL, 0, NULL);
			#endif
		}

	#endif

	// ====================================================

	printf("Included modules: (SHUTDOWN)  ");
	#ifdef INCLUDE_FILES
		printf("FOS  ");
	#endif
	#ifdef INCLUDE_MONITOR
		printf("MON  ");
	#endif
	#ifdef INCLUDE_RIDE
		printf("RIDE  ");
	#endif
	printf("\r\n\n");

	while(1) {

		// print prompt and get command line
		uint8_t *temp = NULL;
		xalloc( (uint8_t **) &temp, FF_MAX_LFN );
		#ifdef INCLUDE_FILES
			f_getcwd( (TCHAR *) temp, (FF_MAX_LFN - strlen((char *) PROMPT) - 20) );
		#endif
		if(*temp && (*temp != ':')) {
			strcat((char *) temp, "\r\n");
			strcat((char *) temp, (char *) PROMPT);
			cputs((char *) temp);
		}
		else cputs((char *) PROMPT);
		xfree((uint8_t **) &temp);
		getLine(NULL);

		// system shutdown
		if(iscmd("shutdown", (const char *) cLine) || iscmd("SHUTDOWN", (const char *) cLine)) {
			#ifndef SANDBOX
				OFF = 0;
				TRISBbits.TRISB5 = 0;	// set the OFF# line low and that shuts down the power supply module
			#endif
			break;
		}

		#ifdef INCLUDE_MONITOR

		// invoke monitor
		if(iscmd("mon", (const char *) cLine) || iscmd("MON", (const char *) cLine)) {
			monMain(NULL);	// use the monitor in interactive mode
			continue;
		}

		#endif

		#ifdef INCLUDE_RIDE

		// RIDE
		if(iscmd("ride", (const char *) cLine) || iscmd("RIDE", (const char *) cLine)) {
			RIDE();
			continue;
		}

		#endif

		#ifdef INCLUDE_FILES

		// FOS
		if(iscmd("fos", (const char *) cLine) || iscmd("FOS", (const char *) cLine)) {
			char cs[5];
			strcpy(cs, "help");
			fopsMain((uint8_t *) cs, 0);
			continue;
		}

		// try to execute FileOps command
		// NOTE: This must be AFTER all other checks for known commands
		// (not using the built-in interactive mode here because it will prevent from adding external commands)
		int8_t result = fopsMain(cLine, 1);
		if(result != FR_OK) {
			fopsError(result);
			continue;
		}

		#endif

	}

	// will never get here
	return 0;

}

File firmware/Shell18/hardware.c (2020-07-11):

#include "hardware.h"
#include "console.h"
#include "xmem.h"

#ifdef INCLUDE_FILES
#include "FatFs/source/diskio.h"
#include "FatFs/source/ff.h"
#include "fileops.h"
#endif

uint8_t xmem[XMEM_SIZE];	// default managed memory array in the internal RAM

#ifndef SANDBOX

__persistent uint8_t crystal_osc = 0;			// set in 1 if an external crystal oscillator is running
__persistent uint8_t stage = 0;					// used for oscillator switch and measuring the clock frequency
__persistent volatile uint32_t freq_cntr_int;	// used for measuring the clock frequency
__persistent volatile uint32_t freq_cntr_ext;	// used for measuring the clock frequency
__at(0x000) uint16_t varC;
__at(0x002) uint8_t *varD;

uint16_t T0val = 0;			// calculated value for the Timer 0 system tick counter
// uint8_t tblregs[4];		// array for saving/restoring the TBL regs

#define saveTBL()    { /* memcpy(tblregs, (uint8_t *) &TABLAT, 4); */ }
#define restoreTBL() { /* memcpy((uint8_t *) &TABLAT, tblregs, 4); */ }

#define TBLaddr(addr) { \
			TBLPTRU = (uint8_t) ((uint32_t) addr >> 16); \
			TBLPTRH = (uint8_t) ((uint32_t) addr >> 8); \
			TBLPTRL = (uint8_t) addr; \
		}

#endif


void memW(uint32_t addr, uint8_t val) {
	#ifndef SANDBOX
		if(isDataRAM(addr)) {	// addresses in this range are considered as access to the internal data RAM
			*( (volatile uint8_t *) (addr - DATA_RAM) ) = val;
		}
		else {
			saveTBL();
			TBLaddr(addr);
			TABLAT = val;
			asm("TBLWT*");
			restoreTBL();
		}
	#else
		sandbox[addr] = val;
	#endif
}


uint8_t memR(uint32_t addr) {
	#ifndef SANDBOX
		uint8_t dreg;
		if(isDataRAM(addr)) {	// addresses in this range are considered as access to the internal data RAM
			dreg = *( (volatile uint8_t *) (addr - DATA_RAM) );
		}
		else {
			saveTBL();
			TBLaddr(addr);
			asm("TBLRD*");
			dreg = TABLAT;
			restoreTBL();
		}
	#else
		uint8_t dreg = sandbox[addr];
	#endif
	return dreg;
}


void memSet(uint32_t addr, uint8_t val, uint32_t n) {
	#ifndef SANDBOX
		if(isDataRAM(addr)) {
			memset( (uint8_t *) (addr - DATA_RAM), val, n);
		}
		else {
			saveTBL();
			TBLaddr(addr);
			TABLAT = val;
			while(n--) asm("TBLWT*+");
			restoreTBL();
		}
	#else
		memset( (uint8_t *) &sandbox[addr], val, n);
	#endif
}


void memMove(uint32_t dst, uint32_t src, uint32_t n) {

	#ifndef SANDBOX

	uint32_t d = dst;
	uint32_t s = src;
	uint8_t da = isDataRAM(d);
	uint8_t sa = isDataRAM(s);

	if(!da && sa) {			// moving from data RAM to external memory
		uint8_t *sp = (uint8_t *) (s - DATA_RAM);
		saveTBL();
		TBLaddr(d);
		while(n--) {	// the blocks are in different memories and can't overlap, so no need for direction check
			TABLAT = *(sp++);
			asm("TBLWT*+");
		}
		restoreTBL();
	}

	else if(da && !sa) {	// moving from external memory to data RAM
		uint8_t *dp = (uint8_t *) (d - DATA_RAM);
		saveTBL();
		TBLaddr(s);
		while(n--) {	// the blocks are in different memories and can't overlap, so no need for direction check
			asm("TBLRD*+");
			*(dp++) = TABLAT;
		}
		restoreTBL();
	}

	else if(!da && !sa) {	// both blocks are in external memory
		if( (s < d) && ((s+n) > d) ) {
			s += n; d += n;
			while(n--) memW(--d, memR(--s));
		}
		else {
			while(n--) memW(d++, memR(s++));
		}
	}

	else {					// both blocks are in data RAM - use the standard memmove() function
		memmove( (uint8_t *) (dst - DATA_RAM), (uint8_t *) (src - DATA_RAM), n);
	}

	#else

	memmove( (uint8_t *) &sandbox[dst], (uint8_t *) &sandbox[src], n);

	#endif

}


uint32_t strLen(uint32_t s) {
	uint32_t len;
	#ifndef SANDBOX
		if(isDataRAM(s)) {
			len = strlen( (const char *) (s - DATA_RAM) );
		}
		else {
			saveTBL();
			TBLaddr(s);
			asm("TBLRD*+");
			for(len = 0; TABLAT; len++) asm("TBLRD*+");
			restoreTBL();
		}
	#else
		len = strlen((char *) &sandbox[s]);
	#endif
	return len;
}


int16_t memCmp(uint32_t v1, uint32_t v2, uint32_t n) {
	int16_t res;
	#ifndef SANDBOX
		if(isDataRAM(v1) && isDataRAM(v2)) {
			res = memcmp( (uint8_t *) (v1 - DATA_RAM), (uint8_t *) (v2 - DATA_RAM), n );
		}
		else {
			for(; n && memR(v1) == memR(v2); n--, v1++, v2++);
			res = (n ? (memR(v1) - memR(v2)) : 0);
		}
	#else
		res = memcmp( (uint8_t *) &sandbox[v1], (uint8_t *) &sandbox[v2], n);
	#endif
	return res;
}


#ifndef SANDBOX

void delay_us(uint32_t us) {
	us /= 10;	// 10 microseconds granularity
	OSCCONbits.SCS = 2;	// 0b10;	// switch to the internal oscillator
	while(us--) __delay_us(9);
	if(crystal_osc) OSCCONbits.SCS = 0;	// 0b00;	// return to the external crystal oscillator
}


void delay_ms(uint32_t ms) {
	OSCCONbits.SCS = 2;	// 0b10;	// switch to the internal oscillator
	while(ms--) __delay_ms(1);
	if(crystal_osc) OSCCONbits.SCS = 0;	// 0b00;	// return to the external crystal oscillator
}


void LCALL(uint32_t addr) {
	//asm("bra LABEL2");
	//asm("LABEL1:");
	LJUMP(addr);
	//asm("LABEL2:");
	//asm("rcall LABEL1");
}


void regStore(void) {
	if(STORE_ADDR) memMove(STORE_ADDR, DATA_RAM, 0x1000);
}
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
